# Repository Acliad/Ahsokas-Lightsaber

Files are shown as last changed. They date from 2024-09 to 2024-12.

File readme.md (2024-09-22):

# Ahsoka Tano's Lightsaber
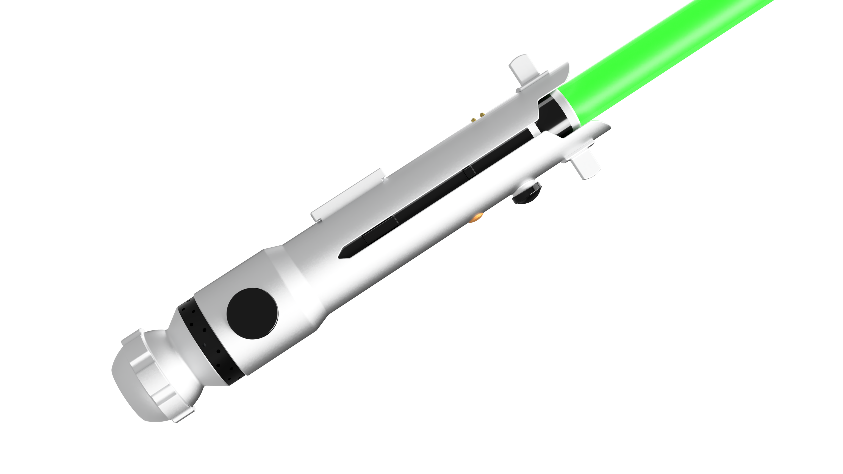
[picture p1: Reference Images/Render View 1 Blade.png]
Render of Lightsaber


<figure style="float: right; margin-left: 25px; width: 200px;">
  Image of Lightsaber V1
  <figcaption>First complete build (minus brass contacts)</figcaption>
</figure>

This repo contains documentation and source files for my build of Ahsoka Tano's lightsaber from Star Wars: The Clone Wars.

# TODO:
- [ ] Write complete documentation for repository

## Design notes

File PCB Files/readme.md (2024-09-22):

This folder contains all the PCBs involved in the build.

## PCBs
- `Encoder Board`: This board holds the rotary encoder for settings adjustments (or whatever you like)
- `Power Button Board`: This board holds the main power button for turning the saber on and off
- `Power Core Board`: This board is the guts of the lightsaber. It houses the MCU, LED driver circuitry, and the battery charging circuitry

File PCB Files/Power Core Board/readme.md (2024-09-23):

This board contains all the control and driver circuitry for the lightsaber's power core. The original prototype was built with an [Adafruit RP2040 Prop-Maker Feather](https://learn.adafruit.com/adafruit-rp2040-prop-maker-feather/overview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). This board is designed to have the same outline and generally accomplish the same feature set. The primary functional differences are this Power Core board:

- Uses an STM32L4 instead of a RP2040
- Uses a 6-axis IMU instead of a 3-axis accelerometer
- Contains a 5V boost converter to power the LEDs at full brightness across battery voltage

## Requirements
The Power Core board main requirements are:

- Contains >= 100MB of onboard storage
- Powered from a single-cell lithium-ion battery
    - Battery connector compatible with JST-PH
- USB-C charging and power from USB-C when connected
- USB-C data connection to the MCU
- 6-axis IMU for motion detection
- 5V boost converter to power the LEDs at full brightness across battery voltage
- 3.3V regulator to power the MCU and connected peripherals
- ~3W audio amplifier
- Terminal block for easy connection to the LED strip and speaker
- EN pin to enable/disable to put device into very low power shutdown mode
- Measurement of battery voltage

## Main Component Selection
- MCU: [STM32L431RC](https://www.st.com/content/ccc/resource/technical/document/datasheet/group3/83/b3/60/f6/b1/cc/47/7e/DM00257211/files/DM00257211.pdf/jcr:content/translations/en.DM002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) (64-pin LQFP, 80MHz, 256KB Flash, 64KB RAM)
- Flash: [W25N01GV](https://www.winbond.com/resource-files/w25n01gv%20revl%20050918%20unsecured.pdf) (1Gb, QSPI)
- IMU: [LSM6DSR](https://www.st.com/resource/en/datasheet/lsm6dsr.pdf) (Accelerometer + Gyroscope)
- Audio Amplifier: [MAX98357](https://www.analog.com/media/en/technical-documentation/data-sheets/max98357a-max98357b.pdf) (3.2W @ 4Ω)
- Battery Charger: [MCP73831](https://ww1.microchip.com/downloads/en/DeviceDoc/MCP73831-Family-Data-Sheet-DS20001984H.pdf) (500mA, 4.2V)
- 5V Boost Converter: [TPS61230ARNSR](https://www.ti.com/lit/ds/symlink/tps61230a.pdf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) (2.4A at 5V out with 2.5V in)
- 3.3V Regulator: [WL9005S5-33](https://wmsc.lcsc.com/wmsc/upload/file/pdf/v2/lcsc/2302091109_WPMtek-Wei-Pan-Microelectronics-WL9005S3-18_C5357196.pdf) (or any SOT-23-5 3.3V regulator, watch IQ and minimize dropout voltage)

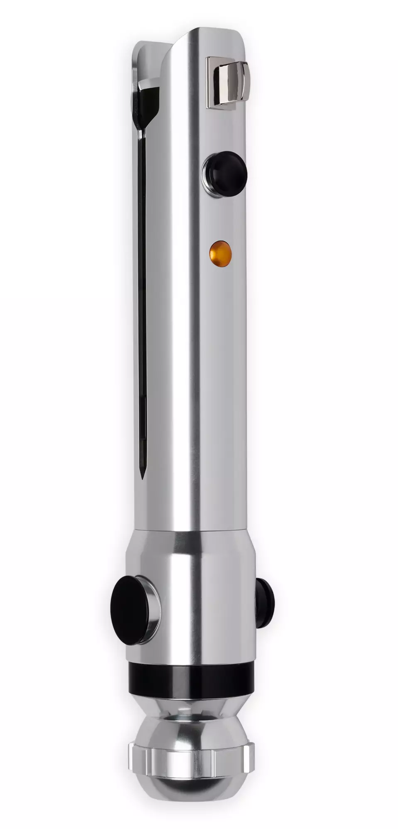
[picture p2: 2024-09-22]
Reference Images/View 1.png

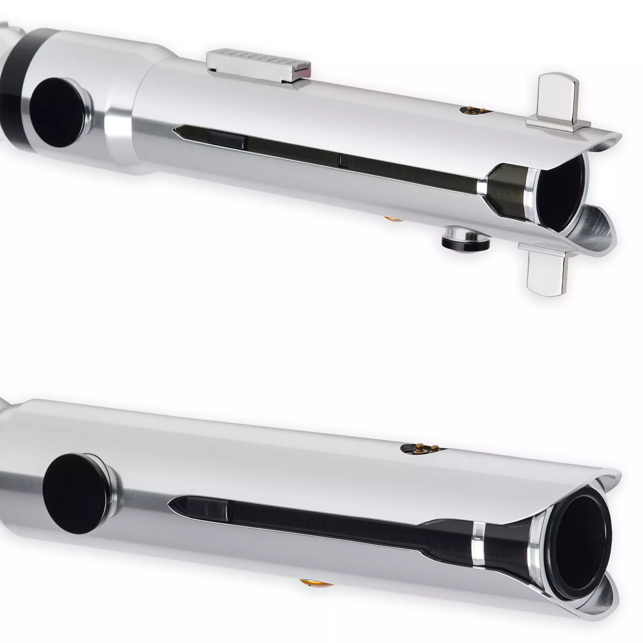
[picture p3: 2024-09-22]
Reference Images/View 5.webp

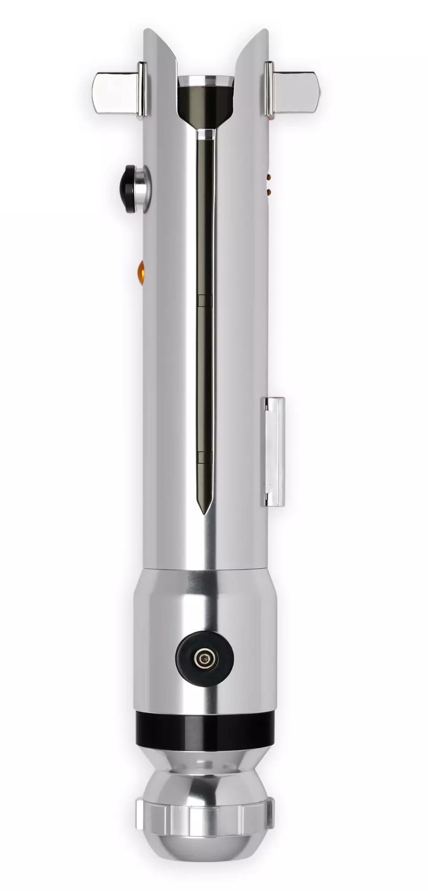
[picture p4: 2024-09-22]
Reference Images/View 3.png

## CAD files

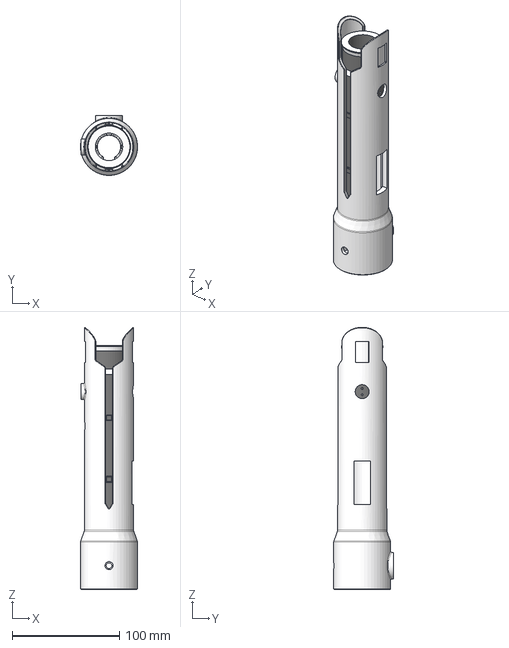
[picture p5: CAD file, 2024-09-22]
Mechanical/Solids/Main Body.stp
53.3 x 55.9 x 244.8 mm

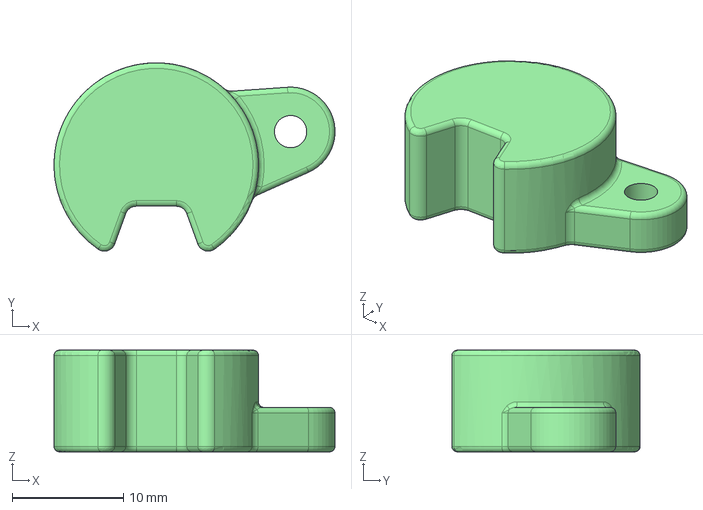
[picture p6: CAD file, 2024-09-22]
Mechanical/Solids/Battery Keeper.stp
25.3 x 16.9 x 9.15 mm

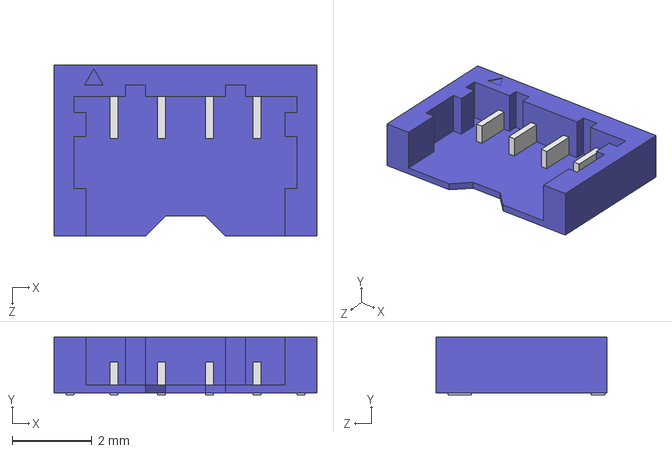
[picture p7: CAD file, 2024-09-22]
PCB Files/Encoder Board/Mechanical/BM04B-ACHSS-A-GAN-ETF.STEP
6.60 x 1.45 x 4.30 mm

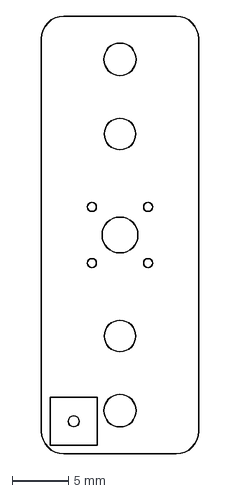
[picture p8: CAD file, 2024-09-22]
PCB Files/Power Button Board/Mechanical/Board Outline And Placement.dxf
14.0 x 39.0 mm

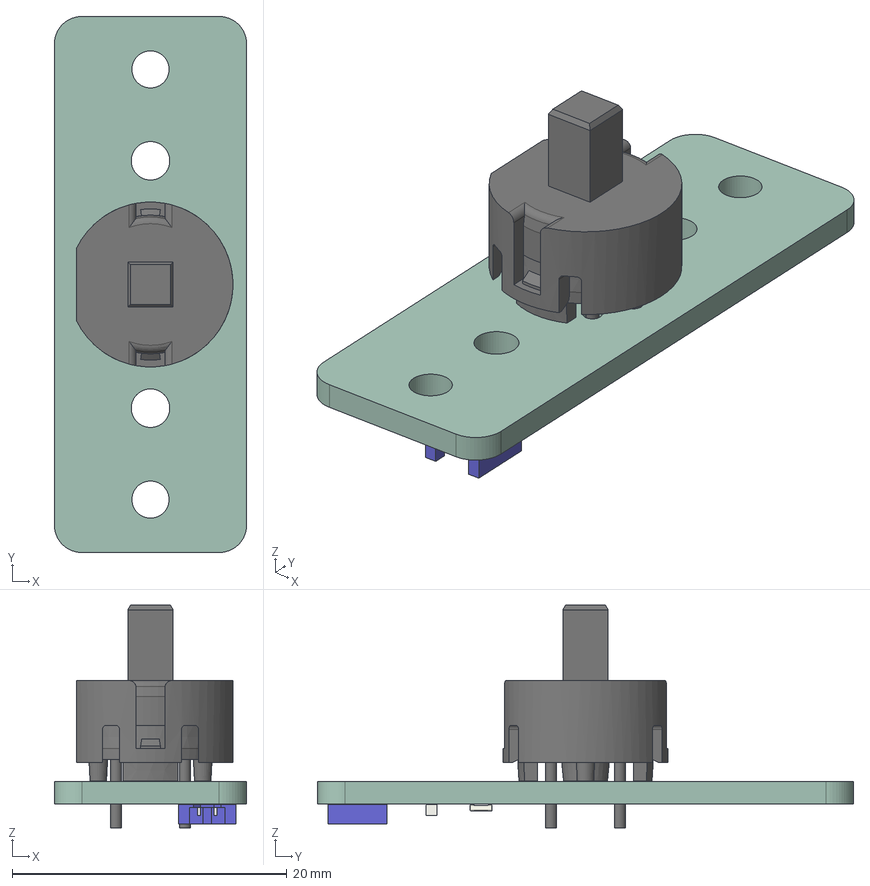
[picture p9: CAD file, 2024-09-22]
PCB Files/Power Button Board/Power Button Board.step
14.0 x 39.0 x 16.2 mm
D6L90F1LFS v4
C_0603_1608Metric
R_0603_1608Metric
BM02B-ACHSS-GAN-ETF v1
Power Button Board_PCB

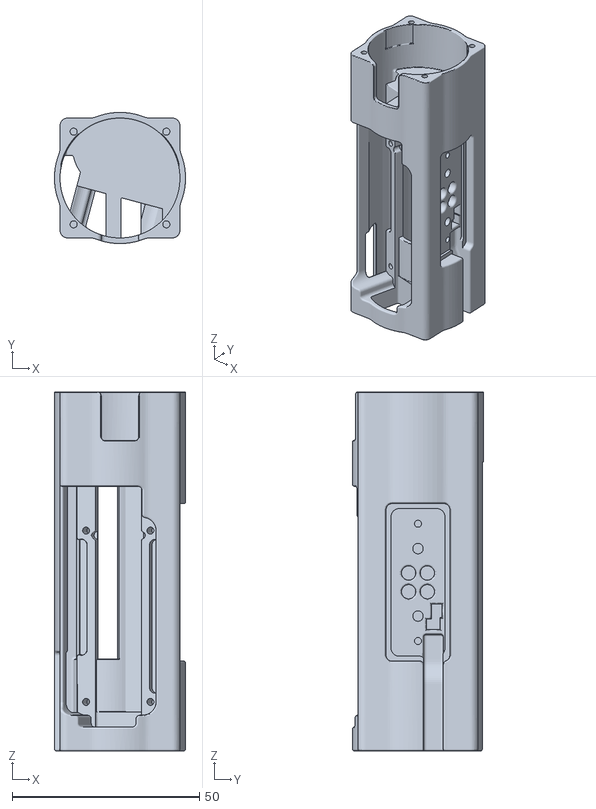
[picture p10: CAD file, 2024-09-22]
Mechanical/Meshes/Carrier.stl
35.0 x 35.0 x 95.8

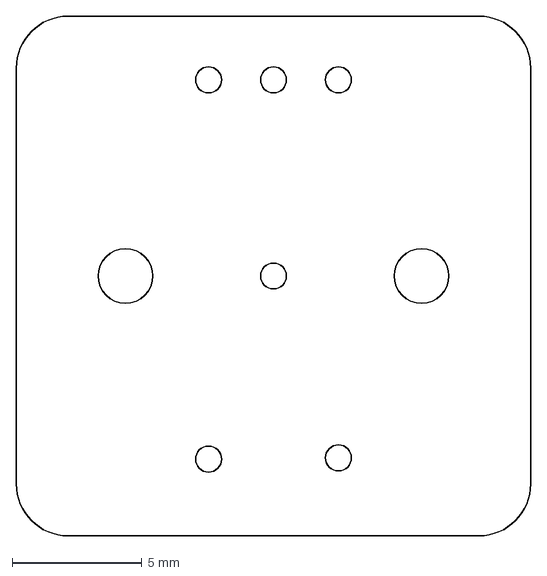
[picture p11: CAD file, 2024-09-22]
PCB Files/Encoder Board/Mechanical/Encoder Board Outline.dxf
19.8 x 20.0 mm

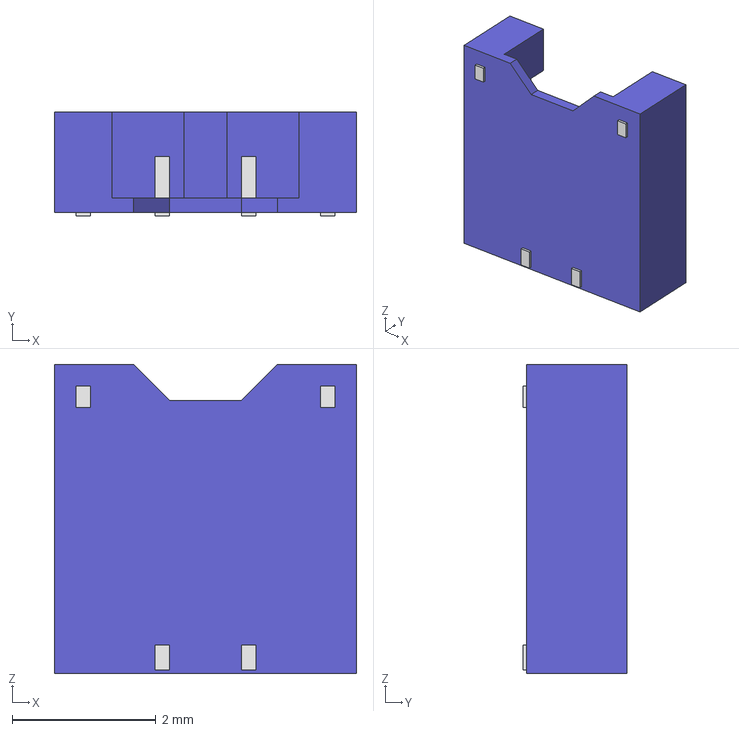
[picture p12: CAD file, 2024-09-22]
PCB Files/Power Button Board/Mechanical/JST_ACH_BM02B-ACHSS-GAN-ETF_1x02-1MP_P1.20mm_Vertical.step
4.20 x 1.45 x 4.30 mm

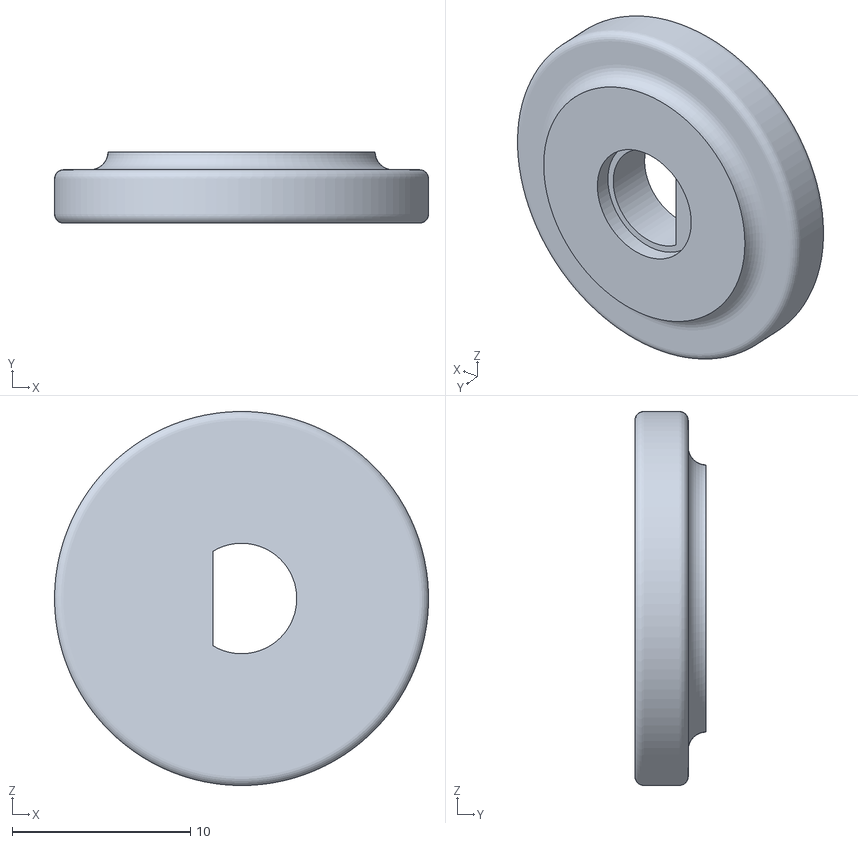
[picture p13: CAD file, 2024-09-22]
Mechanical/Meshes/Encoder Knob.stl
21.0 x 4.00 x 21.0

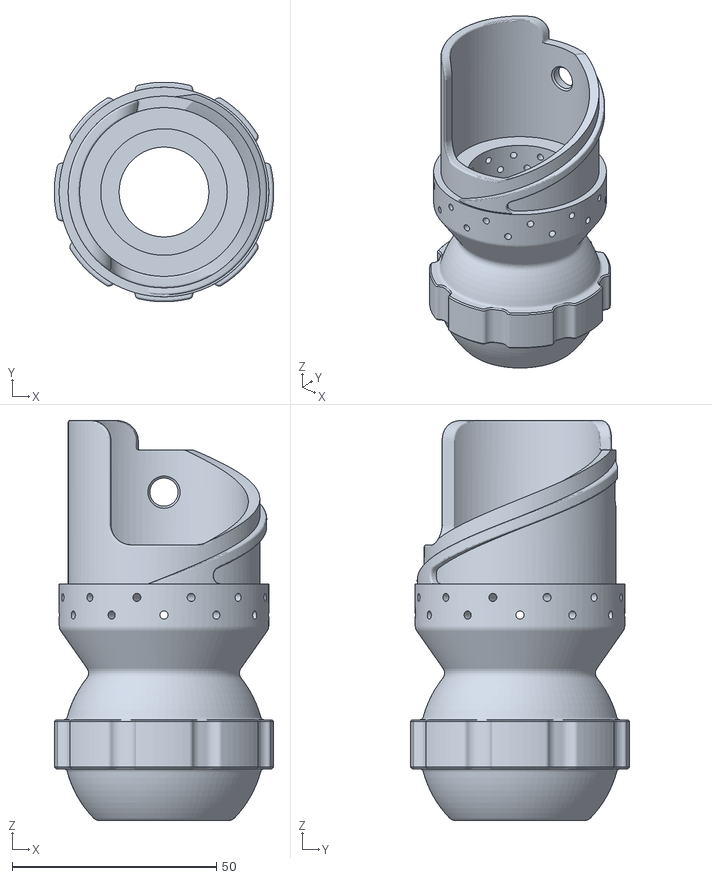
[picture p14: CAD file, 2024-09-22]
Mechanical/Meshes/Bottom Body.stl
53.8 x 53.8 x 98.0

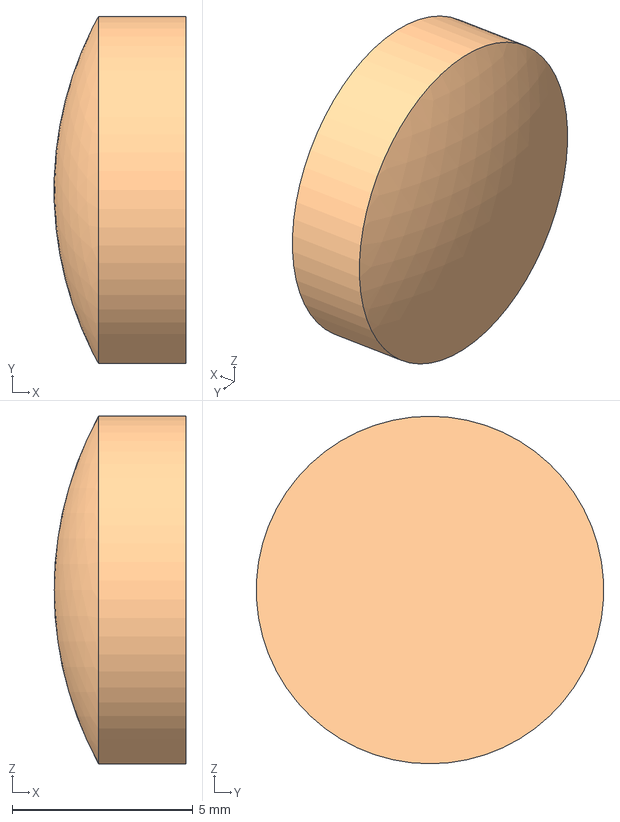
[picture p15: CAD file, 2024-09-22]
Mechanical/Solids/Bead.stp
3.63 x 9.59 x 9.60 mm

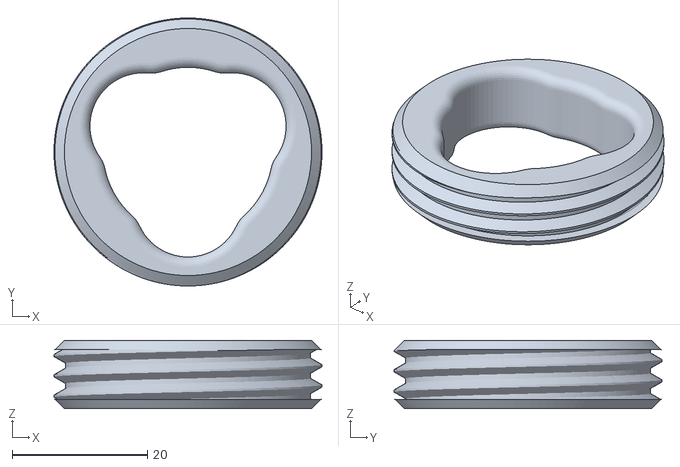
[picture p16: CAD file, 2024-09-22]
Mechanical/Meshes/Carrier Keeper.stl
39.6 x 39.6 x 10.1

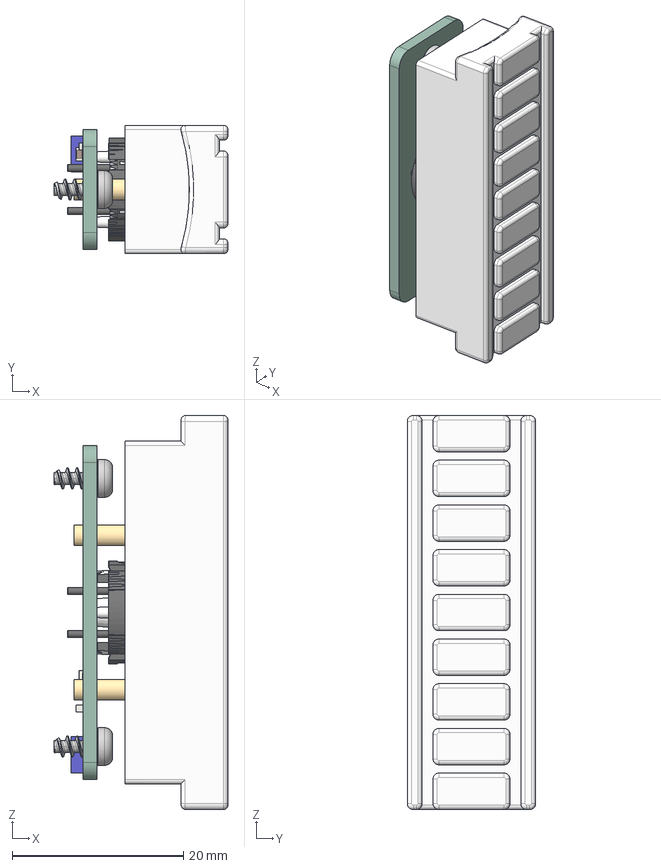
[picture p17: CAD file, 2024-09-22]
Mechanical/Solids/Power Button Cap.stp
20.3 x 15.0 x 46.0 mm
D6L90F1LFS_PART1
BM02B-ACHSS-GAN-ETF
D6L90F1LFS v4
C_0603_1608Metric
R_0603_1608Metric
BM02B-ACHSS-GAN-ETF v1
Power Button Board_PCB
Alignment Rod x 2
Spacer
99461A928_Phillips Rounded Head Thread-Forming Screws x 2

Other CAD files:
Mechanical/Meshes/Main Body.stl
Mechanical/Meshes/Battery Keeper.stl
Mechanical/Solids/LED Strip Keeper.stp
Mechanical/Meshes/Bead.stl
Mechanical/Solids/Bottom Body.stp
Mechanical/Meshes/Acorn Nut Feature.stl
Mechanical/Meshes/Blade Setscrew Cap.stl
Mechanical/Meshes/Bottom Bolt Cap.stl
Mechanical/Meshes/Bottom Bolt Insert.stl
Mechanical/Meshes/LED Strip Keeper.stl
Mechanical/Meshes/Nut.stl
Mechanical/Meshes/Power Button Cap.stl
Mechanical/Meshes/Wing.stl
Mechanical/Solids/Acorn Nut Feature.stp
Mechanical/Solids/Blade Setscrew Cap.stp
Mechanical/Solids/Bottom Bolt Cap.stp
Mechanical/Solids/Bottom Bolt Insert.stp
Mechanical/Solids/Carrier Keeper.stp
Mechanical/Solids/Carrier.stp
Mechanical/Solids/Encoder Knob.stp
Mechanical/Solids/Nut.stp
Mechanical/Solids/Wing.stp

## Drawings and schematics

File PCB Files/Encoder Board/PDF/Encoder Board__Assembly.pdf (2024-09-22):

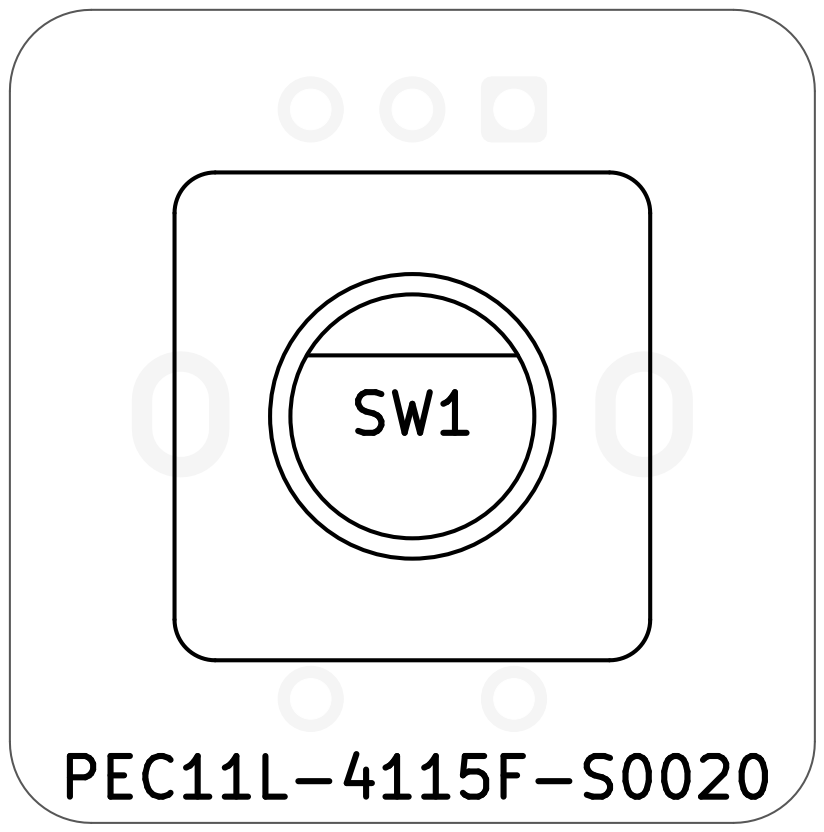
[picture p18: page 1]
D Date: 2024-06-14 Rev: 0; Size: A; Sheet:; Engineer: Isaac; Rex; PEC11L-4115F-S0020 SW1

File: Encoder Board.kicad_pcb Ahsoka's Primary Lightsaber Encoder Board

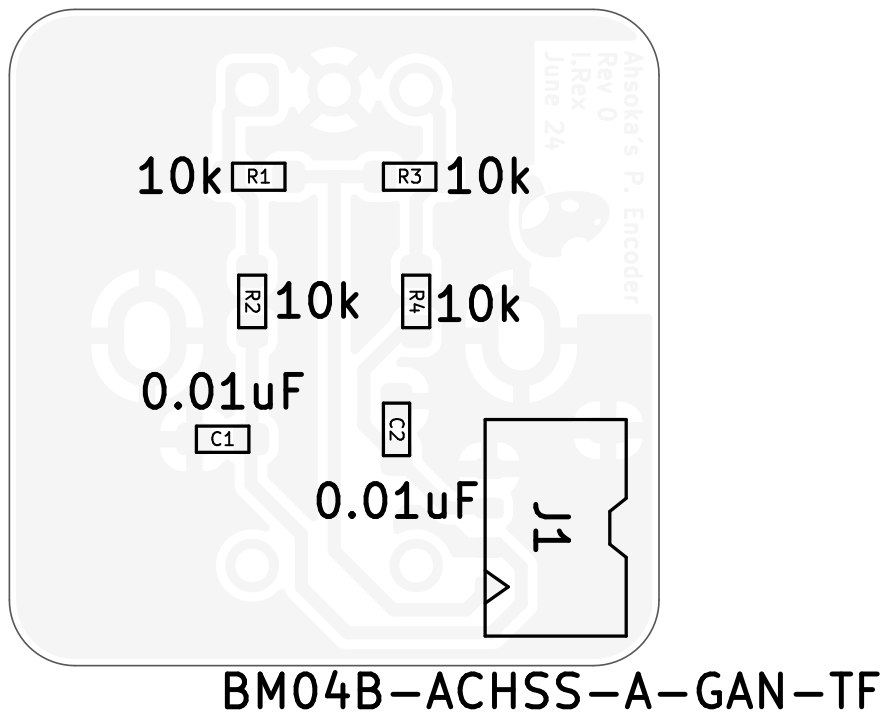
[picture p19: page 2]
D Date: 2024-06-14 Rev: 0; Size: A; Sheet:; Engineer: Isaac; Rex; 10k R3 10k R2 10k R1 BM04B-ACHSS-A-GAN-TF J10.01uF

Ahsoka's P. Encoder Rev 0 June I.Rex 24

File: Encoder Board.kicad_pcb Ahsoka's Primary Lightsaber Encoder Board

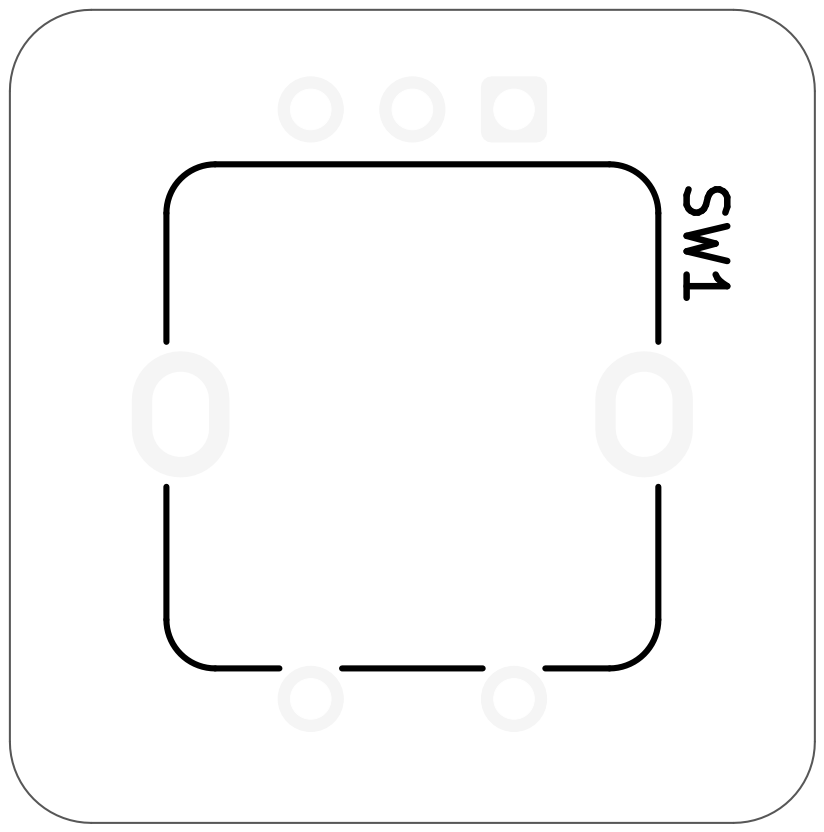
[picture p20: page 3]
D Date: 2024-06-14 Rev: 0; Size: A; Sheet:; Engineer: Isaac; Rex SW1

File: Encoder Board.kicad_pcb Ahsoka's Primary Lightsaber Encoder Board

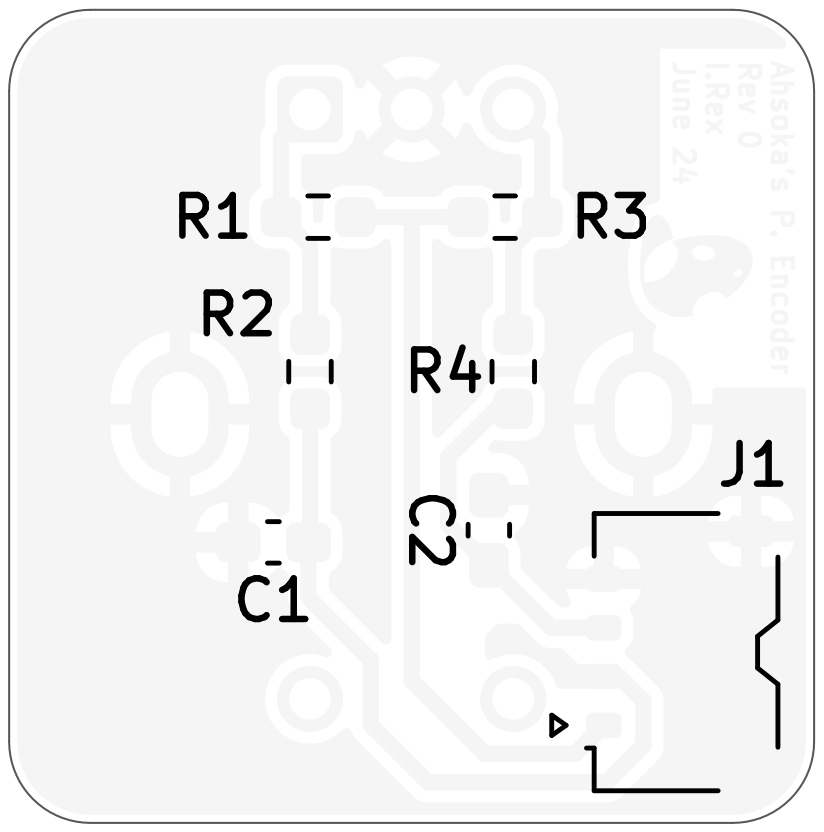
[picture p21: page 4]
D Date: 2024-06-14 Rev: 0; Size: A; Sheet:; Engineer: Isaac; Rex

Ahsoka's P. Encoder Rev 0 June I.Rex 24

File: Encoder Board.kicad_pcb Ahsoka's Primary Lightsaber Encoder Board

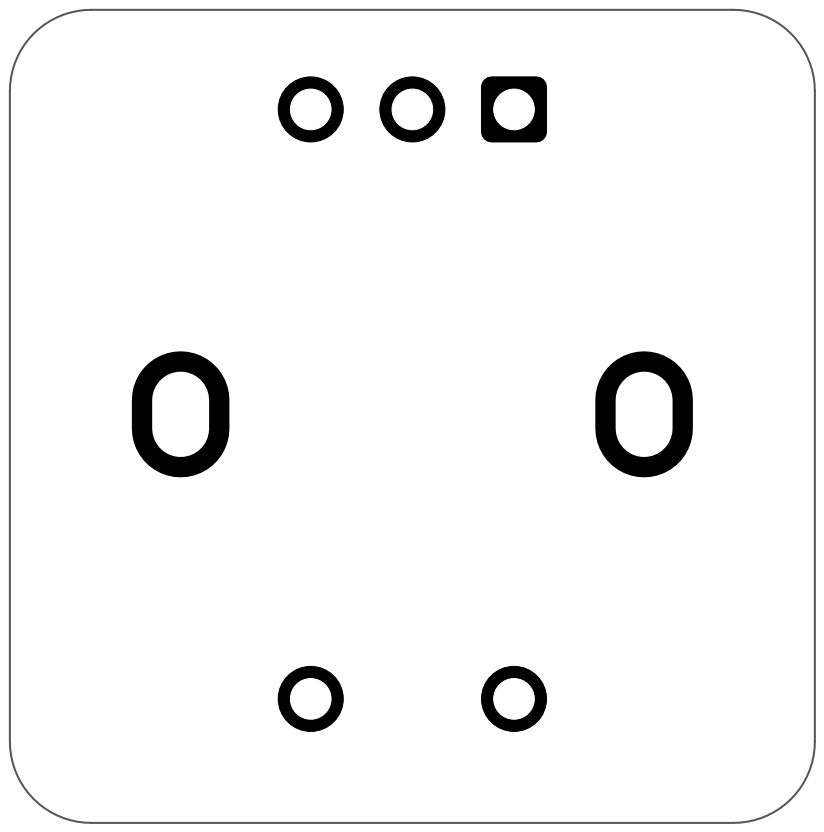
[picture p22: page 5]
D Date: 2024-06-14 Rev: 0; Size: A; Sheet:; Engineer: Isaac; Rex

File: Encoder Board.kicad_pcb Ahsoka's Primary Lightsaber Encoder Board

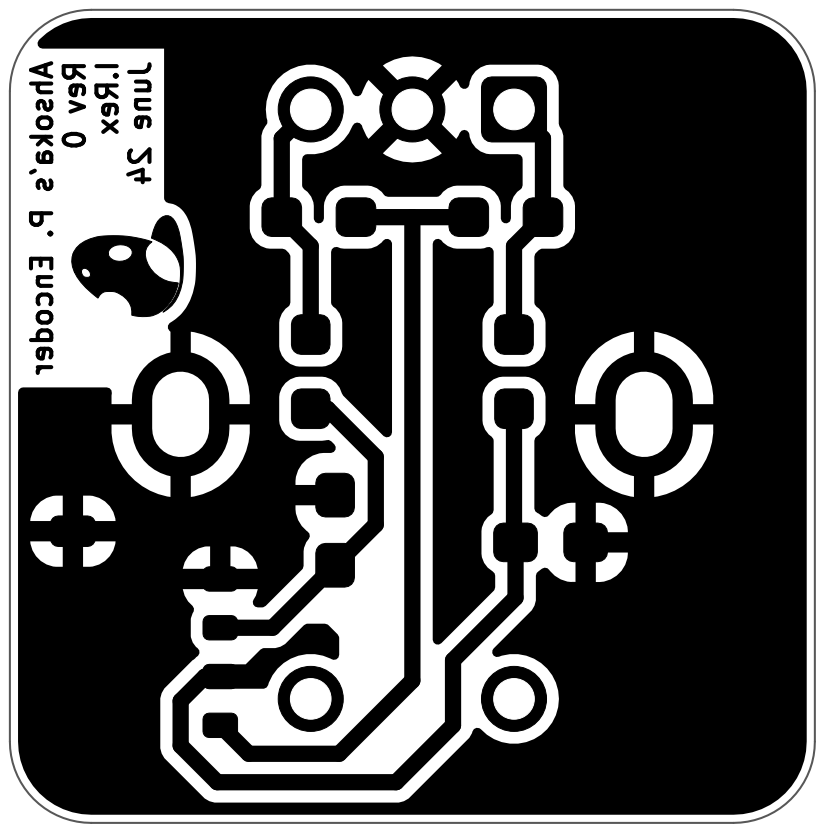
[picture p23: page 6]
D Date: 2024-06-14 Rev: 0; Size: A; Sheet:; Engineer: Isaac; Rex Ahsoka's P. Encoder Rev 0 I.Rex June 24

File: Encoder Board.kicad_pcb Ahsoka's Primary Lightsaber Encoder Board

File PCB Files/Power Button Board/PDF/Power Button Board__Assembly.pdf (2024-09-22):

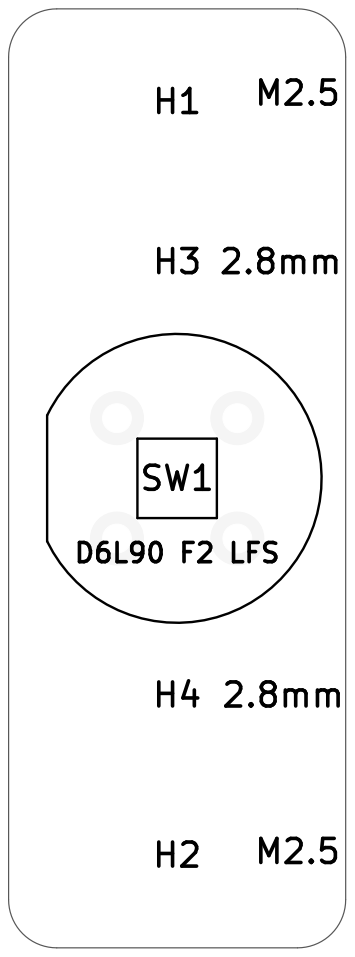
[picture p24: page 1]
D Date: Rev:; Size: A; Sheet:; M2.5 D6L90 F2 LFS SW1 H2

File: Power Button Board.kicad_pcb Engineer:

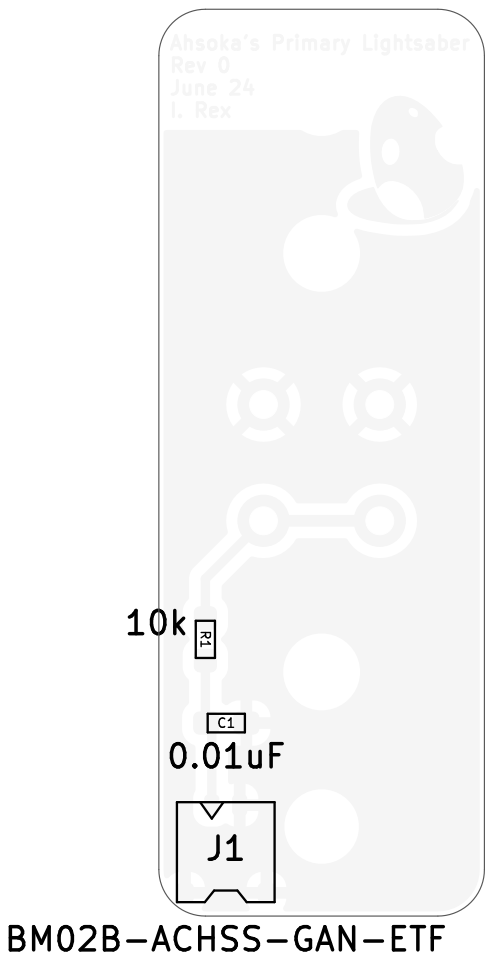
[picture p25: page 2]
Ahsoka's; Primary; Lightsaber Rev 0; June 24 I. Rex; D Date: Rev:; Size: A; Sheet:; R1 BM02B-ACHSS-GAN-ETF

File: Power Button Board.kicad_pcb Engineer:

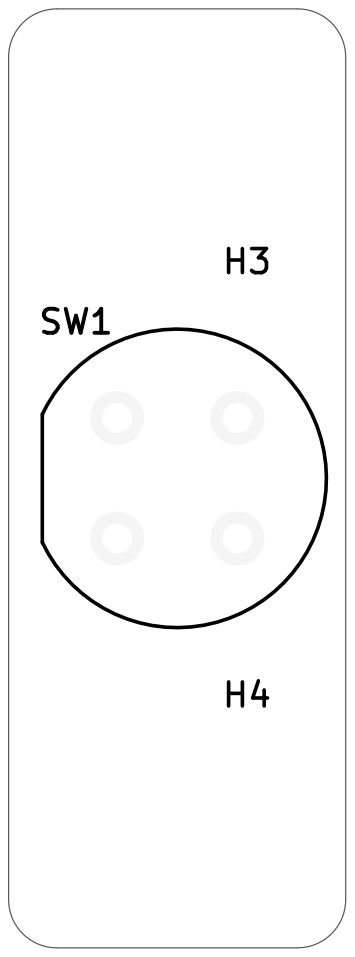
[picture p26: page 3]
D Date: Rev:; Size: A; Sheet:

File: Power Button Board.kicad_pcb Engineer:

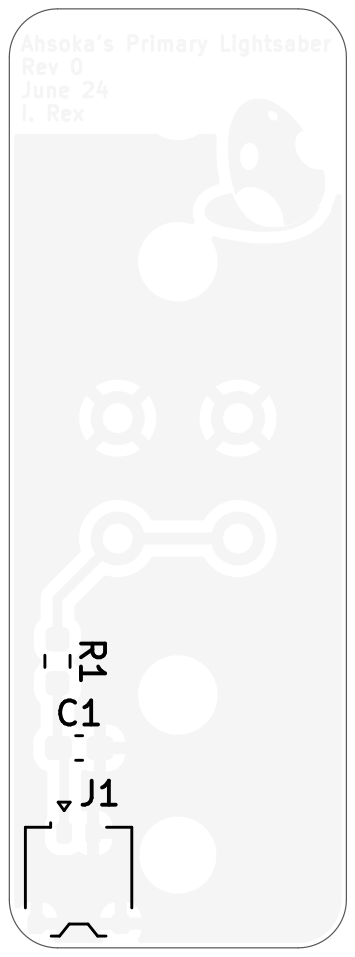
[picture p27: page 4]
Ahsoka's; Primary; Lightsaber Rev 0; June 24 I. Rex; D Date: Rev:; Size: A; Sheet:

File: Power Button Board.kicad_pcb Engineer:

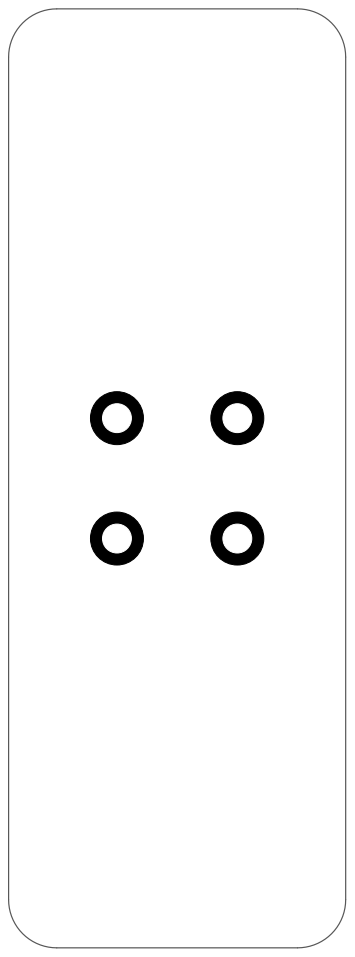
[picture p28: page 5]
D Date: Rev:; Size: A; Sheet:

File: Power Button Board.kicad_pcb Engineer:

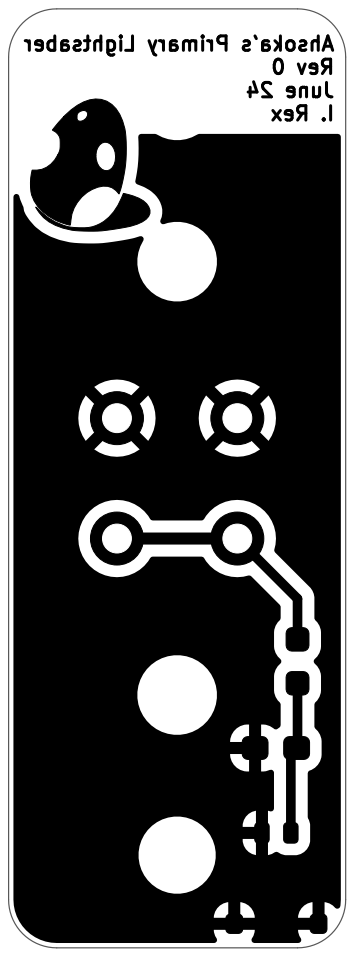
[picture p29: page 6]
D Date: Rev:; Size: A; Sheet:

File: Power Button Board.kicad_pcb Engineer:

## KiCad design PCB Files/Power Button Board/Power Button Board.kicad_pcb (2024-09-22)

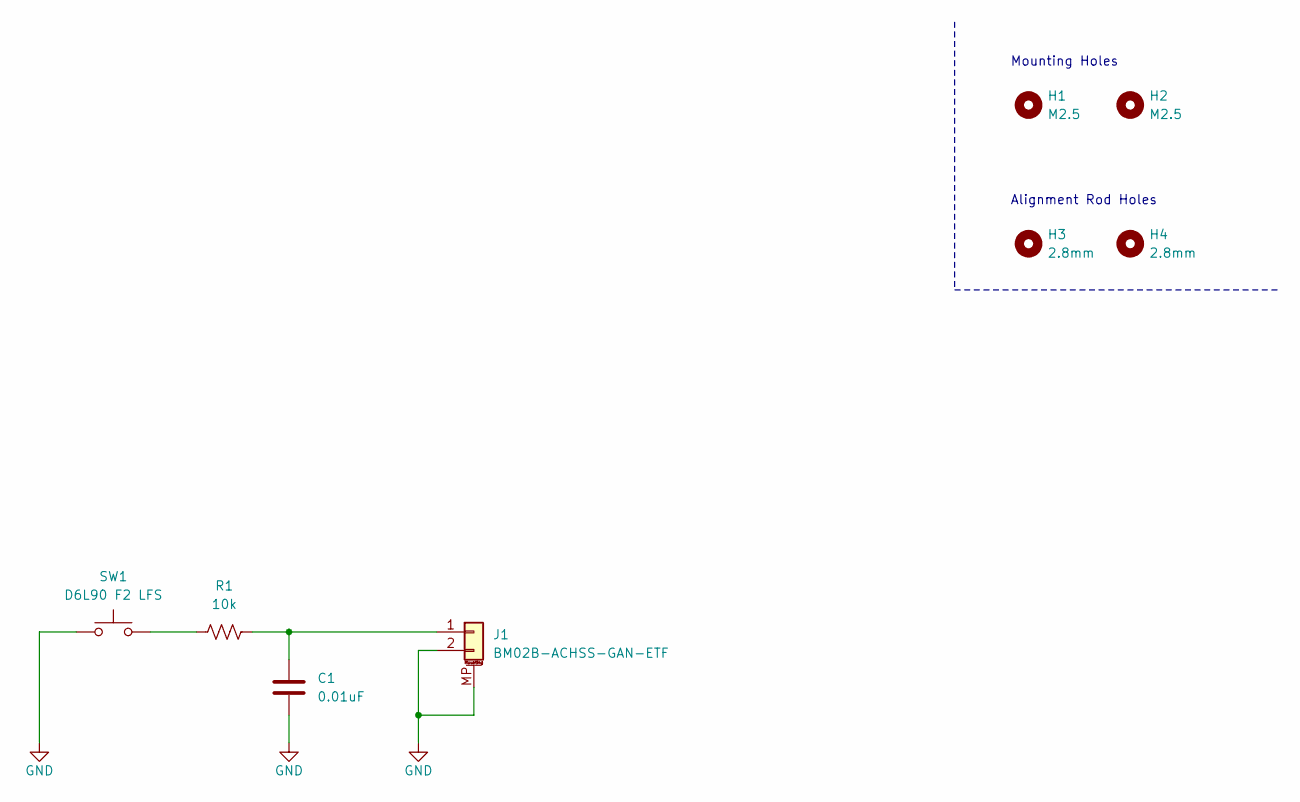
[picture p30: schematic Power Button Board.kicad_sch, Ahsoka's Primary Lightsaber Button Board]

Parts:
C1: 0.01uF; C_0603_1608Metric_Pad1.08x0.95mm_HandSolder; DigiKey PN 1276-CL10B103KB8NNNDCT-ND
H1, H2: M2.5; MountingHole_2.7mm_M2.5
H3, H4: 2.8mm; MountingHole_2.8mm_ReducedCourtyard
J1: BM02B-ACHSS-GAN-ETF; JST_ACH_BM02B-ACHSS-GAN-ETF_1x02-1MP_P1.20mm_Vertical; DigiKey PN 455-BM02B-ACHSS-GAN-ETFCT-ND
R1: 10k; R_0603_1608Metric_Pad0.98x0.95mm_HandSolder; DigiKey PN CR0603-FX-1002ELFCT-ND
SW1: D6L90 F2 LFS; SW_CK_D6LxxxxLFS; DigiKey PN 401-2019-ND

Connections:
GND: C1.2, J1.2, J1.MP (MountPin), SW1.1
unnamed: C1.1, J1.1, R1.2
unnamed: R1.1, SW1.2

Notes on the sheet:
Alignment Rod Holes
Mounting Holes

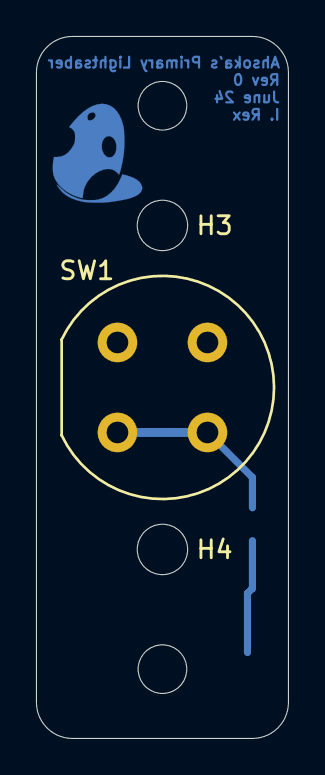
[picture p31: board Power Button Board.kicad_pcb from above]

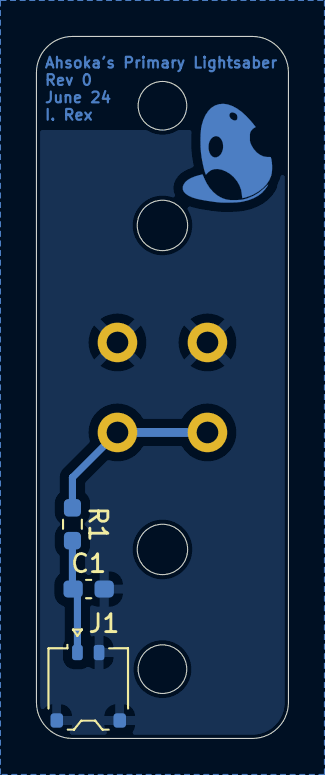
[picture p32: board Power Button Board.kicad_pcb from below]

Board: 2 copper layers, 14.0 x 39.0 mm, 8 parts (3 on the bottom side), 3 nets.

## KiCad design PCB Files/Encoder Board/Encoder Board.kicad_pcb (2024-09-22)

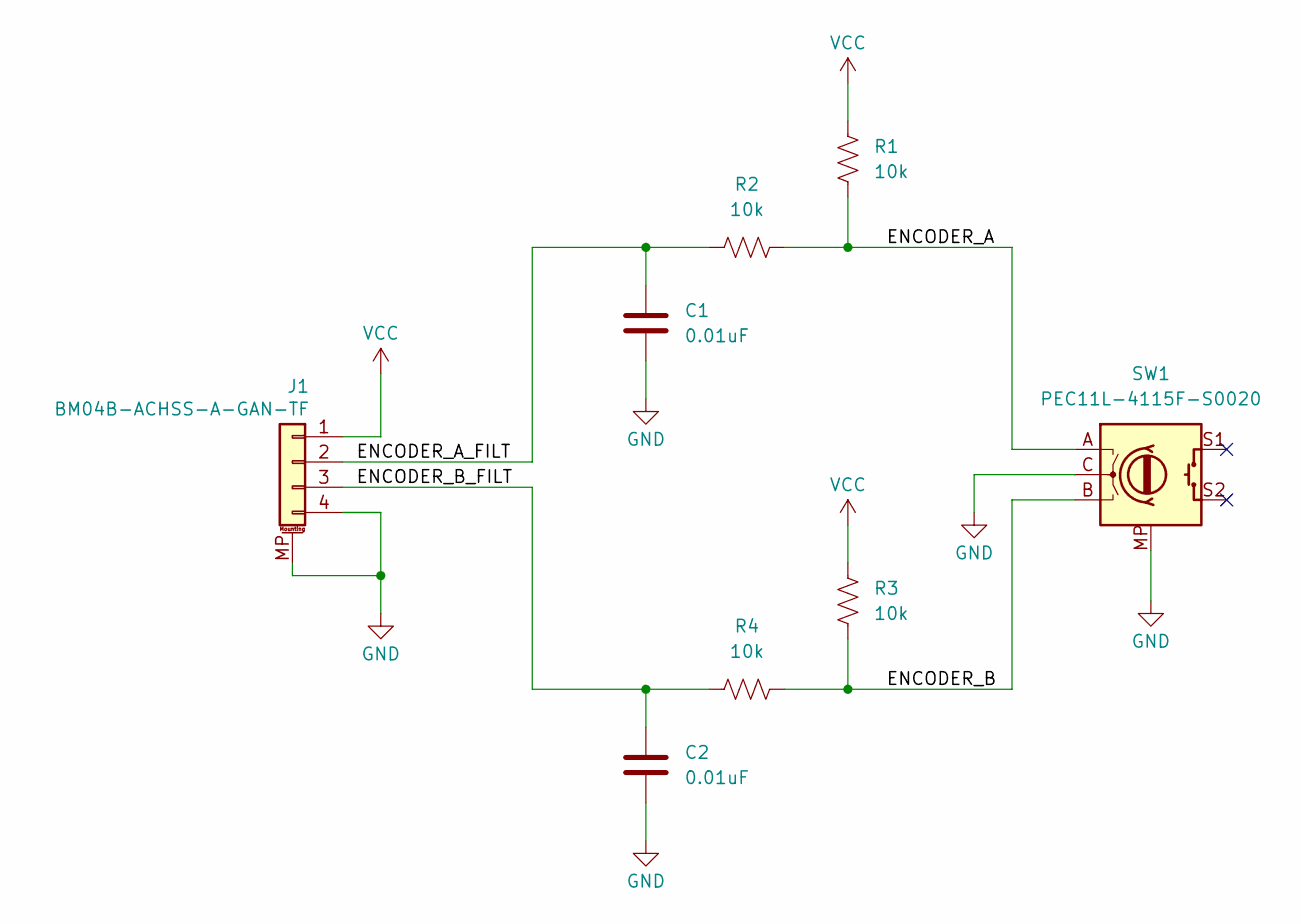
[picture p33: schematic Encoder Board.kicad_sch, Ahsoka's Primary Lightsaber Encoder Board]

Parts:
C1, C2: 0.01uF; C_0603_1608Metric_Pad1.08x0.95mm_HandSolder; DigiKey PN 1276-CL10B103KB8NNNDCT-ND
J1: BM04B-ACHSS-A-GAN-TF; JST_ACH_BM04B-ACHSS-A-GAN-ETF_1x04-1MP_P1.20mm_Vertical; DigiKey PN 455-BM04B-ACHSS-A-GAN-TFCT-ND
R1, R2, R3, R4: 10k; R_0603_1608Metric_Pad0.98x0.95mm_HandSolder; DigiKey PN CR0603-FX-1002ELFCT-ND
SW1: PEC11L-4115F-S0020; RotaryEncodoer_Bourns_Vertical_PEC11L-4xxxF-Sxxxx_ShieldPads; DigiKey PN PEC11L-4115F-S0020-ND

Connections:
/ENCODER_A: R1.2, R2.2, SW1.A
/ENCODER_A_FILT: C1.1, J1.2, R2.1
/ENCODER_B: R3.2, R4.2, SW1.B
/ENCODER_B_FILT: C2.1, J1.3, R4.1
GND: C1.2, C2.2, J1.4, J1.MP (MountPin), SW1.C, SW1.MP
VCC: J1.1, R1.1, R3.1

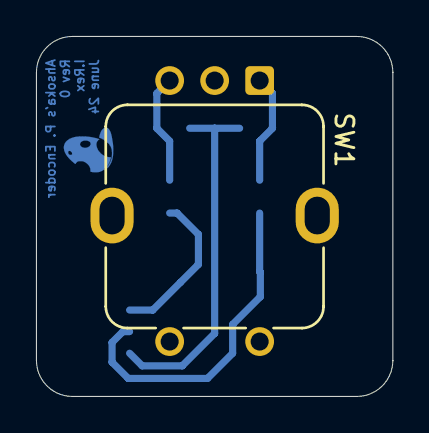
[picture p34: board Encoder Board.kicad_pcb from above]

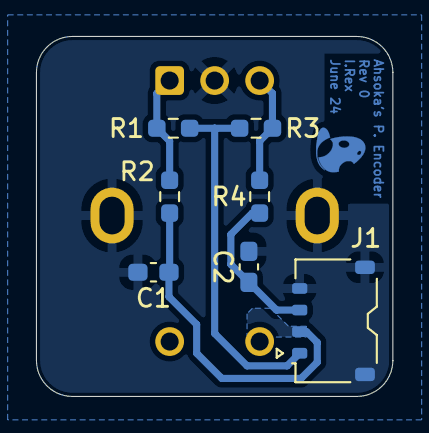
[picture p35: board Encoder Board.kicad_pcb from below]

Board: 4 copper layers, 19.8 x 20.0 mm, 8 parts (7 on the bottom side), 6 nets.

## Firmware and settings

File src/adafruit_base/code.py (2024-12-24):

# SPDX-FileCopyrightText: 2023 Liz Clark for Adafruit Industries
#
# SPDX-License-Identifier: MIT
import board # type: ignore
import audiobusio
import rotaryio
import alarm
import colorsys
import saber_settings
import time
from adafruit_debouncer import Button
from digitalio import DigitalInOut, Direction, Pull
import neopixel
import adafruit_lis3dh
from blade import Blade

# CUSTOMIZE SENSITIVITY HERE: smaller numbers = more sensitive to motion
ENCODER_SENSITIVITY = 0.01
HIT_THRESHOLD = 120
SWING_THRESHOLD = 145
VOLUME_MODE_COLOR = (255, 100, 0)

DEFAULT_BLADE_COLOR = (0, 100, 255) # Cyan
DEFAULT_VOLUME = 1.0

# The time the lightsaber is in off mode before going to deep sleep
SLEEP_TIMEOUT_TIME_SECONDS = 10*60

# The amount of time to debounce button presses
BUTTON_DEBOUNCE_TIME_S = 0.035

# Load settings
blade_settings = saber_settings.SaberSettings("/settings.json")
# Ensure defaults are set (this should probably be done in the settings class with an optional defaults dict)
if blade_settings.blade_color is None:
    blade_settings.blade_color = DEFAULT_BLADE_COLOR
# TODO: Volume not yet implemented
if blade_settings.volume is None:
    blade_settings.volume = DEFAULT_VOLUME
# Values need to be normalized for colorsys
blade_hsv = saber_settings.rgb_to_hsv([x / 255 for x in blade_settings.blade_color]) 
blade_volume = blade_settings.volume

# Set up the neopixels
num_pixels = 129
pixels = neopixel.NeoPixel(board.EXTERNAL_NEOPIXELS, num_pixels, auto_write=False)
pixels.brightness = 0.8

# enable external power pin
# provides power to the neopixels
external_power = DigitalInOut(board.EXTERNAL_POWER)
external_power.direction = Direction.OUTPUT
external_power.value = True
# Make sure the neopixels are off
pixels.fill(0)
pixels.show()

# Create the audio out object
audio = audiobusio.I2SOut(board.I2S_BIT_CLOCK, board.I2S_WORD_SELECT, board.I2S_DATA)

# Power button
power_btn_pin = DigitalInOut(board.D13)
power_btn_pin.direction = Direction.INPUT
power_btn_pin.pull = Pull.UP
switch = Button(power_btn_pin, short_duration_ms = 20, long_duration_ms = 1000, interval = BUTTON_DEBOUNCE_TIME_S)

# Rotary encoder
encoder = rotaryio.IncrementalEncoder(board.D12, board.D11)
last_rotary_position = encoder.position
def get_encoder_delta():
    global last_rotary_position
    position = encoder.position
    delta = position - last_rotary_position
    last_rotary_position = position
    return delta

# Accelerometer
i2c = board.I2C()
int1 = DigitalInOut(board.ACCELEROMETER_INTERRUPT)
lis3dh = adafruit_lis3dh.LIS3DH_I2C(i2c, int1=int1)
# Accelerometer Range (can be 2_G, 4_G, 8_G, 16_G)
lis3dh.range = adafruit_lis3dh.RANGE_2_G
lis3dh.set_tap(1, HIT_THRESHOLD)

# Set up the blade
blade = Blade(pixels, audio, color=blade_settings.blade_color)

# Main state machine
def animate_hue_config():
    temp_hsv = blade_hsv.copy()
    hue_delta = ENCODER_SENSITIVITY
    while hue_delta <= 1:
        temp_hsv[0] = (blade_hsv[0] + hue_delta)%1
        blade.color = colorsys.hsv_to_rgb(temp_hsv[0], temp_hsv[1], temp_hsv[2])
        blade.update()
        hue_delta += ENCODER_SENSITIVITY
        time.sleep(0.001)
    
def animate_sat_config():
    temp_hsv = blade_hsv.copy()
    sat_delta = ENCODER_SENSITIVITY
    while sat_delta <= 1:
        temp_hsv[1] = (blade_hsv[1] + sat_delta)%1
        blade.color = colorsys.hsv_to_rgb(temp_hsv[0], temp_hsv[1], temp_hsv[2])
        blade.update()
        sat_delta += ENCODER_SENSITIVITY
        time.sleep(0.001)

def animate_volume_config():
    # Linearly inerpolate between the current color and VOLUME_MODE_COLOR
    step_size = 50 # Number of steps to take to get to the final color
    temp_color = blade.color
    slopes = [(VOLUME_MODE_COLOR[i] - temp_color[i]) / step_size for i in range(3)]
    while [round(c) for c in temp_color] != list(VOLUME_MODE_COLOR):
        temp_color = [min(max(temp_color[i] + slopes[i], 0), 255) for i in range(3)]
        blade.color = [round(c) for c in temp_color]
        blade.update()
        # time.sleep(0.001)

time_turned_off = time.monotonic()
config_pages = ['hue', 'saturation', 'volume']
active_config_page = config_pages[0]
last_config_page = None

# Track the state of the state machine. Modes are:
#   - startup: The lightsaber is starting up
#   - run: The lightsaber is running normally
#   - shutdown: The lightsaber is shutting down
#   - retracted: The lightsaber is retracted but can be turned on
#   - off: The lightsaber is off and can go to sleep. Requires a long press to turn on
#   - config: The lightsaber is in configuration mode

mode = 'off' # Default to off
while True:
    switch.update()
    blade.update()
    # startup
    if mode == 'startup':
        blade.startup()
        mode = 'run'
    # default
    elif mode == 'run':
        x, y, z = lis3dh.acceleration
        accel_total = x * x + y * y + z * z 
        if accel_total >= SWING_THRESHOLD and blade.mode == "run":
            blade.mode = 'swing'
        if switch.short_count > 0:
            mode = 'shutdown'
        if switch.long_press:
            print("Config...")
            # Call get_encoder_delta() to clear the encoder state
            get_encoder_delta()
            mode = 'config'
            blade.mode = 'config'
    # turn off
    elif mode == 'shutdown':
        blade.shutdown()
        mode = 'retracted'
        time_turned_off = time.monotonic()
    # go to startup from retracted if button is pressed
    elif mode == 'retracted':
        if switch.short_count > 0:
            external_power.value = True
            mode = 'startup'
        # Turn off if the saber has been retracted for a while
        if time.monotonic() - time_turned_off > SLEEP_TIMEOUT_TIME_SECONDS:
            mode = 'off'
    # go to sleep
    elif mode == 'off':
        # From off mode, we want require a long press to turn the saber back on
        if switch.long_press:
            mode = 'startup'
        # Go to sleep if the saber has been off for a while
        if time.monotonic() - time_turned_off > SLEEP_TIMEOUT_TIME_SECONDS:
            print("Going to sleep...")
            external_power.value = False
            # Set up the sleep alarm
            power_btn_pin.deinit()
            edge_alarm = alarm.pin.PinAlarm(board.D13, value=False, pull=True)
            alarm.exit_and_deep_sleep_until_alarms(edge_alarm)

    # config state
    elif mode == 'config':
        encoder_increment = get_encoder_delta() * ENCODER_SENSITIVITY
        if active_config_page == 'hue':
            if last_config_page != active_config_page:
                animate_hue_config()
            
            if encoder_increment:
                blade_hsv[0] += (encoder_increment)%1
                blade.color = colorsys.hsv_to_rgb(blade_hsv[0], blade_hsv[1], blade_hsv[2])
        elif active_config_page == 'saturation':
            if last_config_page != active_config_page:
                animate_sat_config()
            
            if encoder_increment:
                # Saturation of 0 causes the blade to turn off. Set minimum to 0.01
                blade_hsv[1] = min(max(blade_hsv[1] + encoder_increment, 0.01), 1)
                blade.color = colorsys.hsv_to_rgb(blade_hsv[0], blade_hsv[1], blade_hsv[2])
        elif active_config_page == 'volume':
            if last_config_page != active_config_page:
                animate_volume_config()
            if encoder_increment:
                # TODO: implement volume control. I know that this is currenlty bad practice because they name doesn't
                # quite match the function. It will be fixed (or rather completely replaced) in a future commit.
                # Making blade_volume a float just so the rest of the code is consistent with volume being a float
                blade_volume = float(not blade.muted) 
                blade.muted = blade_volume

        last_config_page = active_config_page
        
        if switch.long_press:
            # Save the updated settings
            blade.color = colorsys.hsv_to_rgb(blade_hsv[0], blade_hsv[1], blade_hsv[2])
            blade_settings.blade_color = colorsys.hsv_to_rgb(blade_hsv[0], blade_hsv[1], blade_hsv[2])
            blade_settings.volume = blade_volume
            try:
                blade_settings.save_settings()
            except RuntimeError as e:
                print("Error saving settings. Cannot save while mounted as a drive.\n", e)
            active_config_page = 'hue'
            last_config_page = None
            blade.mode = 'run'
            mode = 'run'
        if switch.short_count > 0:
            active_config_page = config_pages[(config_pages.index(active_config_page) + 1) % len(config_pages)]

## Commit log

2024-09-23 Add links to main components in Power Core docs
2024-09-29 Updated gitignore to add some kicad files
2024-12-24 Fixed no off-mode bug
    [code.py]
